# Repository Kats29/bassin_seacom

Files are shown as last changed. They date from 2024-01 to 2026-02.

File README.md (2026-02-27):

# Bassin Laboratoire SEACom - ISEN

Ce projet vise à remettre le bassin de test du laboratoire SEACom de l'ISEN au goût du jour. Pour cela, une interface Web est déployée sur un serveur Ethernet hébergé sur une carte Beaglebone Black qui communique avec le bassin via un shield customisé.

## TODO

### Partie Logicielle

- écrire une suite de tests exhaustive qui permet de comprendre ce qui doit être envoyé par le backend en fonction des commandes exécutées
- définir les trames de messages dans la documentation
- compléter la description de cette documentation (à partir de "Redémarrage des commandes numériques (RESET)")

### Partie Matérielle

- Imprimer ou découper à la CNC le couvercle du boitier de la carte
- Ajouter la vitre plexi devant les LED
- Produire la nouvelle version de la carte électronique
- acheter les différents composant manquant pour autonomiser le boitier
	- [prise filtre 230V](https://fr.rs-online.com/web/p/filtres-iec/1676800?searchId=2fb21e5c-5856-4a20-a56e-df45db2b0a76) (ça sera serré mais normalement ça passe)
    - [Alim 5V](https://fr.rs-online.com/web/p/alimentations-a-decoupage/0413673?searchId=7ffa1f5d-4cfa-4edf-9e52-69dc6d7725a8)
    - connecteur DB9 de facade

## Installation

### Configuration de la carte Beaglebone

Premièrement, afin d'avoir accès à tous les ports GPIO de la carte, celle-ci doit être démarrée à partir d'une carte SD au lieu de sa mémoire interne. Pour ce faire, téléchargez [la dernière image de Debian pour Beaglenone Black](https://www.beagleboard.org/distros) et flashez-la sur votre carte SD. Faites attention de bien choisir une image et non pas un flasher eMMC (le nom devrait finir par `4GB microSD IoT`).

Puisque les dernières versions ont un serveur nginx préinstallé, c'est ce que ce projet va utiliser.

Afin de vous connecter au Beaglebone, connecter le câble ethernet à votre pc et configurer votre carte réseau pour avoir une IPv4 telle que 192.168.7.4, via la commande `sudo ifconfig enp3s0 192.168.7.4` (en remplaçant enp3s0 par le nom de votre interface réseau).

Une fois la carte SD insérée dans la Beaglebone et celle-ci branchée sur le même réseau que votre ordinateur, vous pourrez ouvrir une console `ssh` grâce à la commande suivante :

```sh
ssh debian@192.168.7.3
```

Le mot de passe par défaut est `temppwd`.

Afin de configurer nginx, ouvrez le fichier `/etc/nginx/sites-enabled/default` et remplacez la ligne `root /var/www` par `root /home/debian/dist`. Enregistrez le fichier.

Finalement, il faut ouvrir le port 3333 de la Beaglebone pour permettre la connection TCP entre l'interface et le backend :

```sh
sudo nft add table ip filter
sudo nft add chain ip filter INPUT { type filter hook input priority 0 \; }
sudo nft add rule ip filter INPUT tcp dport 3333 accept
sudo nft list ruleset # pour vérifier que les règles ont bien été appliquées
sudo nft list ruleset | sudo tee -a /etc/nftables.conf # pour les sauvegarder
```

Vous pouvez maintenant quitter la console `ssh` avec la commande :

```sh
exit
```

### Compilation du projet

La compilation nécessite d'avoir podman, podman-compose et git d'installés sur le pc.
Clonez et compilez le projet GitHub sur votre ordinateur avec les commandes suivantes :

```sh
git clone https://github.com/Kats29/bassin_seacom.git
cd bassin_seacom
podman build .
podman compose run --rm arm-builder
```

Une fois que le projet est bien compilé (penser à vérifier les logs pour cela) vous pouvez envoyer la release sur la Beaglebone via le script `./.send.sh`.

Tapez le mot de passe de la Beaglebone lorsqu'il vous est demandé.

Vous pouvez à présent rouvrir une console `ssh` pour démarrer le backend :

```sh
ssh debian@192.168.7.3
```

Tapez le mot de passe.

```sh
sudo systemctl restart backend.service
```

Si tout va bien, vous devez avoir quelque chose qui ressemble à ci-dessous en tapant la commande  `sudo systemctl status backend.service` :
```sh
● backend.service - Backend du bassin
     Loaded: loaded (/etc/systemd/system/backend.service; enabled; preset: enabled)
     Active: active (running) since Fri 2025-03-14 21:15:03 CET; 5s ago
   Main PID: 2041 (backend)
      Tasks: 1 (limit: 1024)
     Memory: 72.0K
        CPU: 61ms
     CGroup: /system.slice/backend.service
             └─2041 /home/debian/backend

Mar 14 21:15:03 bassin systemd[1]: Started backend.service - Backend du bassin.
Mar 14 21:15:03 bassin backend[2041]: Starting backend...
```

Si vous souhaitez éditer la configuration du service, elle se trouve ici `/etc/systemd/system/backend.service` et nécessite un redémarrage de systemctl via `sudo systemctl daemon-reload`.

### Accès à l'interface

Vous pouvez à présent vous connecter à l'interface depuis votre navigateur internet, en tapant `192.168.7.3:9090` dans la barre d'adresse.

## Branchement

### Installation de la Beaglebone

### Raccordement réseau

### Communication avec le bassin

## Documentation

Une fois le projet cloné, la documentation technique du code peut être générée grâce à la commande :

```sh
make doc
```

La documentation devrait s'ouvrir dans un navigateur. Sinon, elle peut être visualisée dans un navigateur en ouvrant les fichiers `index.html` générés dans `target/doc/common`, `target/armv7-unknown-linux-musleabihf/doc/backend` et `target/wasm32-unknown-unknown/doc/frontend`

## Utilisation

L'accès se fait via deux plateformes : [cockpit](https://192.168.7.3:9090/system) pour le monitoring et le [site web pour le contrôle des bras](http://192.168.7.3/).

Interface de contrôle

### Apparence et organisation

L'interface est constituée d'une seule vue, qui est séparée en trois zones : une vue centrale, et deux panneaux latéraux. En cas de nécéssité, une fenêtre d'erreur peut également s'ouvrir devant la vue centrale.

#### Vue centrale

La vue centrale représente une visualisation de l'état actuel du bassin, ainsi que des commandes prévues.

Sa partie supérieure montre une vue du dessus en séparant les moitiés droite et gauche du bassin. La même séparation est visible sur la partie inférieure, qui elle montre une vue de côté du bassin (pour visualiser la profondeur).

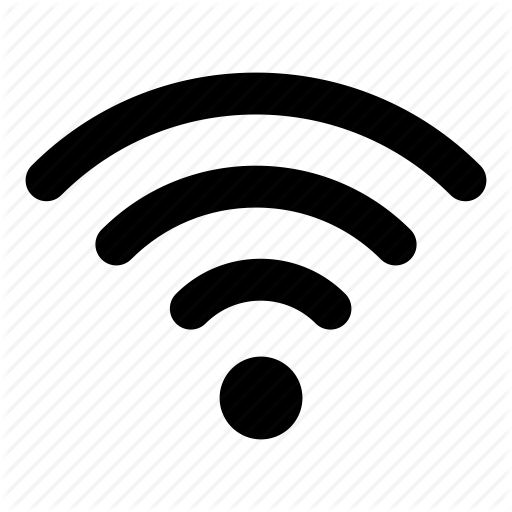
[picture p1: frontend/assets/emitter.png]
Les cadres noirs délimitent les zones où chacun des deux bras peut se déplacer, et les symboles  en noir symbolisent la position actuelle de chaque bras. Les symboles  grisés montrent le prochain mouvement pouvant être ajouté.

#### Panneau gauche

Le panneau latéral gauche montre deux choses :

* Les coordonnées du prochain mouvement à ajouter pour chaque bras.

* L'état actuel du bassin, sous formes d'indicateurs colorés (rouges ou verts, gris si le bassin n'est pas connecté).
	* En face de chaque coordonnée, un indicateur passe au rouge si un mouvement est en cours sur cet axe.
	* Sous les coordonnées, d'autres informations sont données sous cette forme.

#### Panneau droit

Le panneau latéral droit montre simplement la liste des mouvement prévus pour chaque bras, dans l'ordre chronologique.

#### Fenêtre d'erreur

### Commandes d'alimentation

La première chose à faire pour allumer le bassin est de le mettre physiquement sous tension. Une fois que c'est fait, l'alimentation peut être contrôlée à distance par l'interface.

#### Allumer le bassin

Pour allumer le bassin, allez dans le menu `Alimentation` et cliquez sur `Démarrer`. Après un démarrage de cette façon, une commande de RESET (expliquée plus loin) et de remise à l'origine doivent obligatoirement être effectuées dans cet ordre.

Après appui, les indicateurs `Bassin alimenté` et `Bassin démarré` devraient être au vert.

#### Éteindre le bassin

Une fois le bassin sous tension et démarré, le menu `Alimentation` devrait contenir un bouton `Arrêter`, qui doit éteindre le bassin.

Après appui, l'indicateur `Bassin démarré` devrait repasser au rouge.

#### Redémarrage des commandes numériques (RESET)

### Gestion des mouvements

#### Ajouter un mouvement

#### Supprimer un mouvement

#### Modifier un mouvement

### Effectuer un mouvement

#### Commandes générales

#### Commandes par bras

#### Commandes par axe

### Sauvegarde et importation de positions

#### Sauvegarder la configuration

#### Importer une configuration

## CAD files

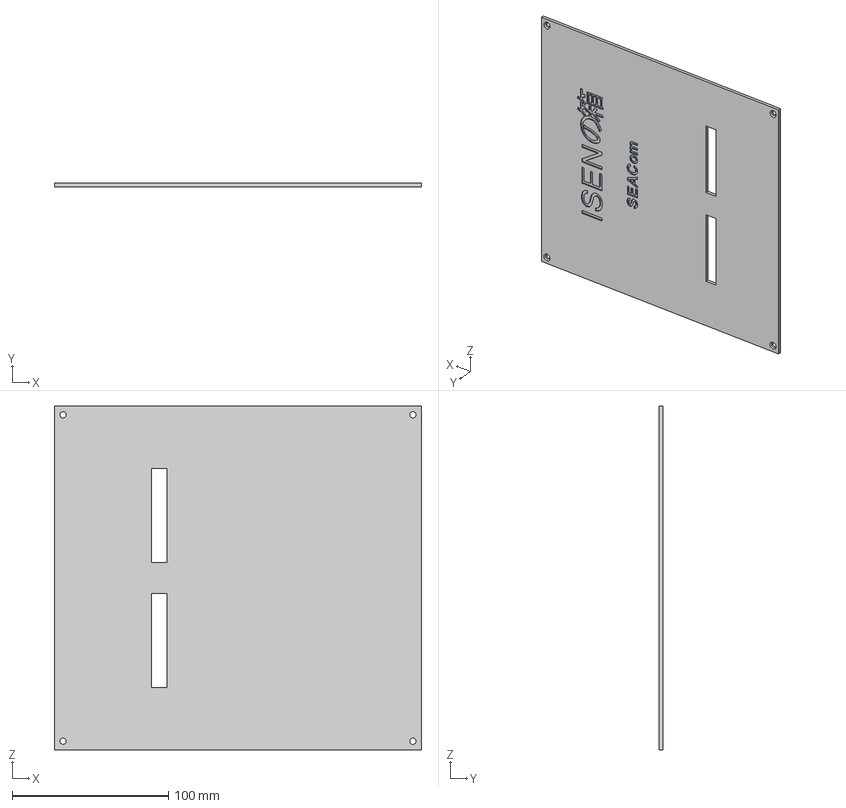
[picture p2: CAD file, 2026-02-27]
modelisation/boitier/couvercle.step
235.0 x 2.50 x 220.0 mm

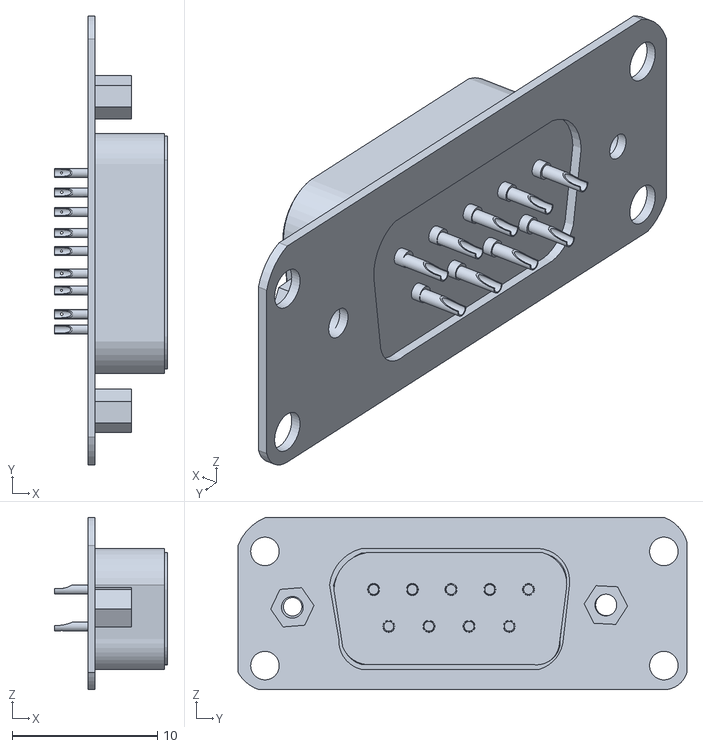
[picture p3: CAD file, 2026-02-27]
modelisation/connecteur_DB9.stl
7.80 x 31.0 x 11.9

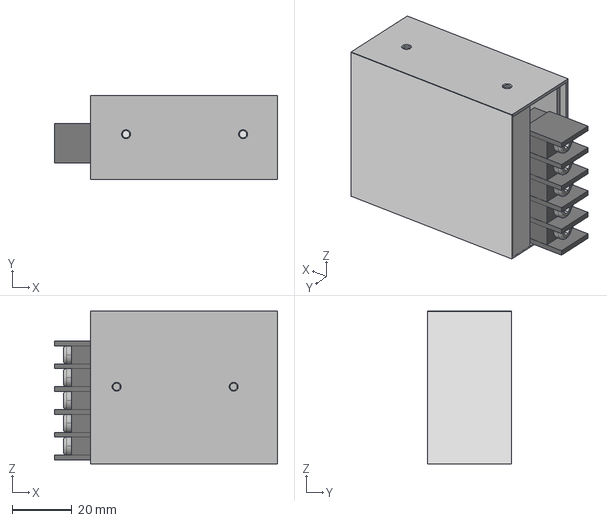
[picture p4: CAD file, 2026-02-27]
modelisation/Alim_5V.stp
74.5 x 28.0 x 51.0 mm

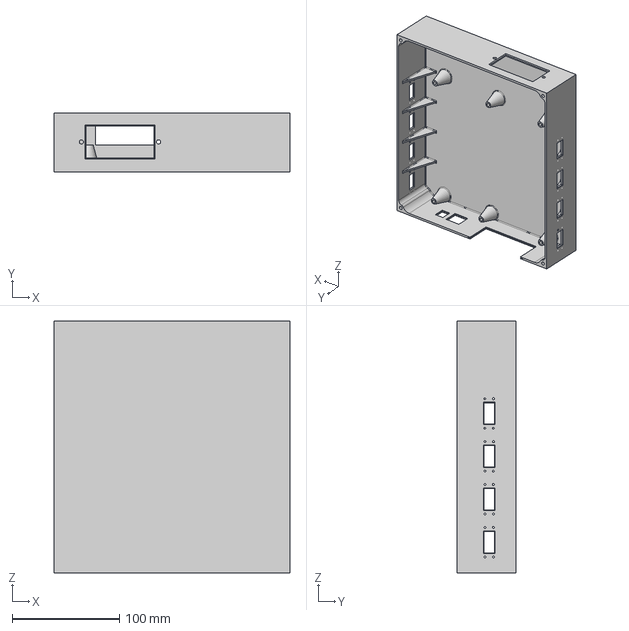
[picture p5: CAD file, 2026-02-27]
modelisation/boitier/Boitier.step
220.0 x 55.0 x 235.0 mm

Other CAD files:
modelisation/boitier/Boitier.f3d
modelisation/boitier/couvercle.f3d

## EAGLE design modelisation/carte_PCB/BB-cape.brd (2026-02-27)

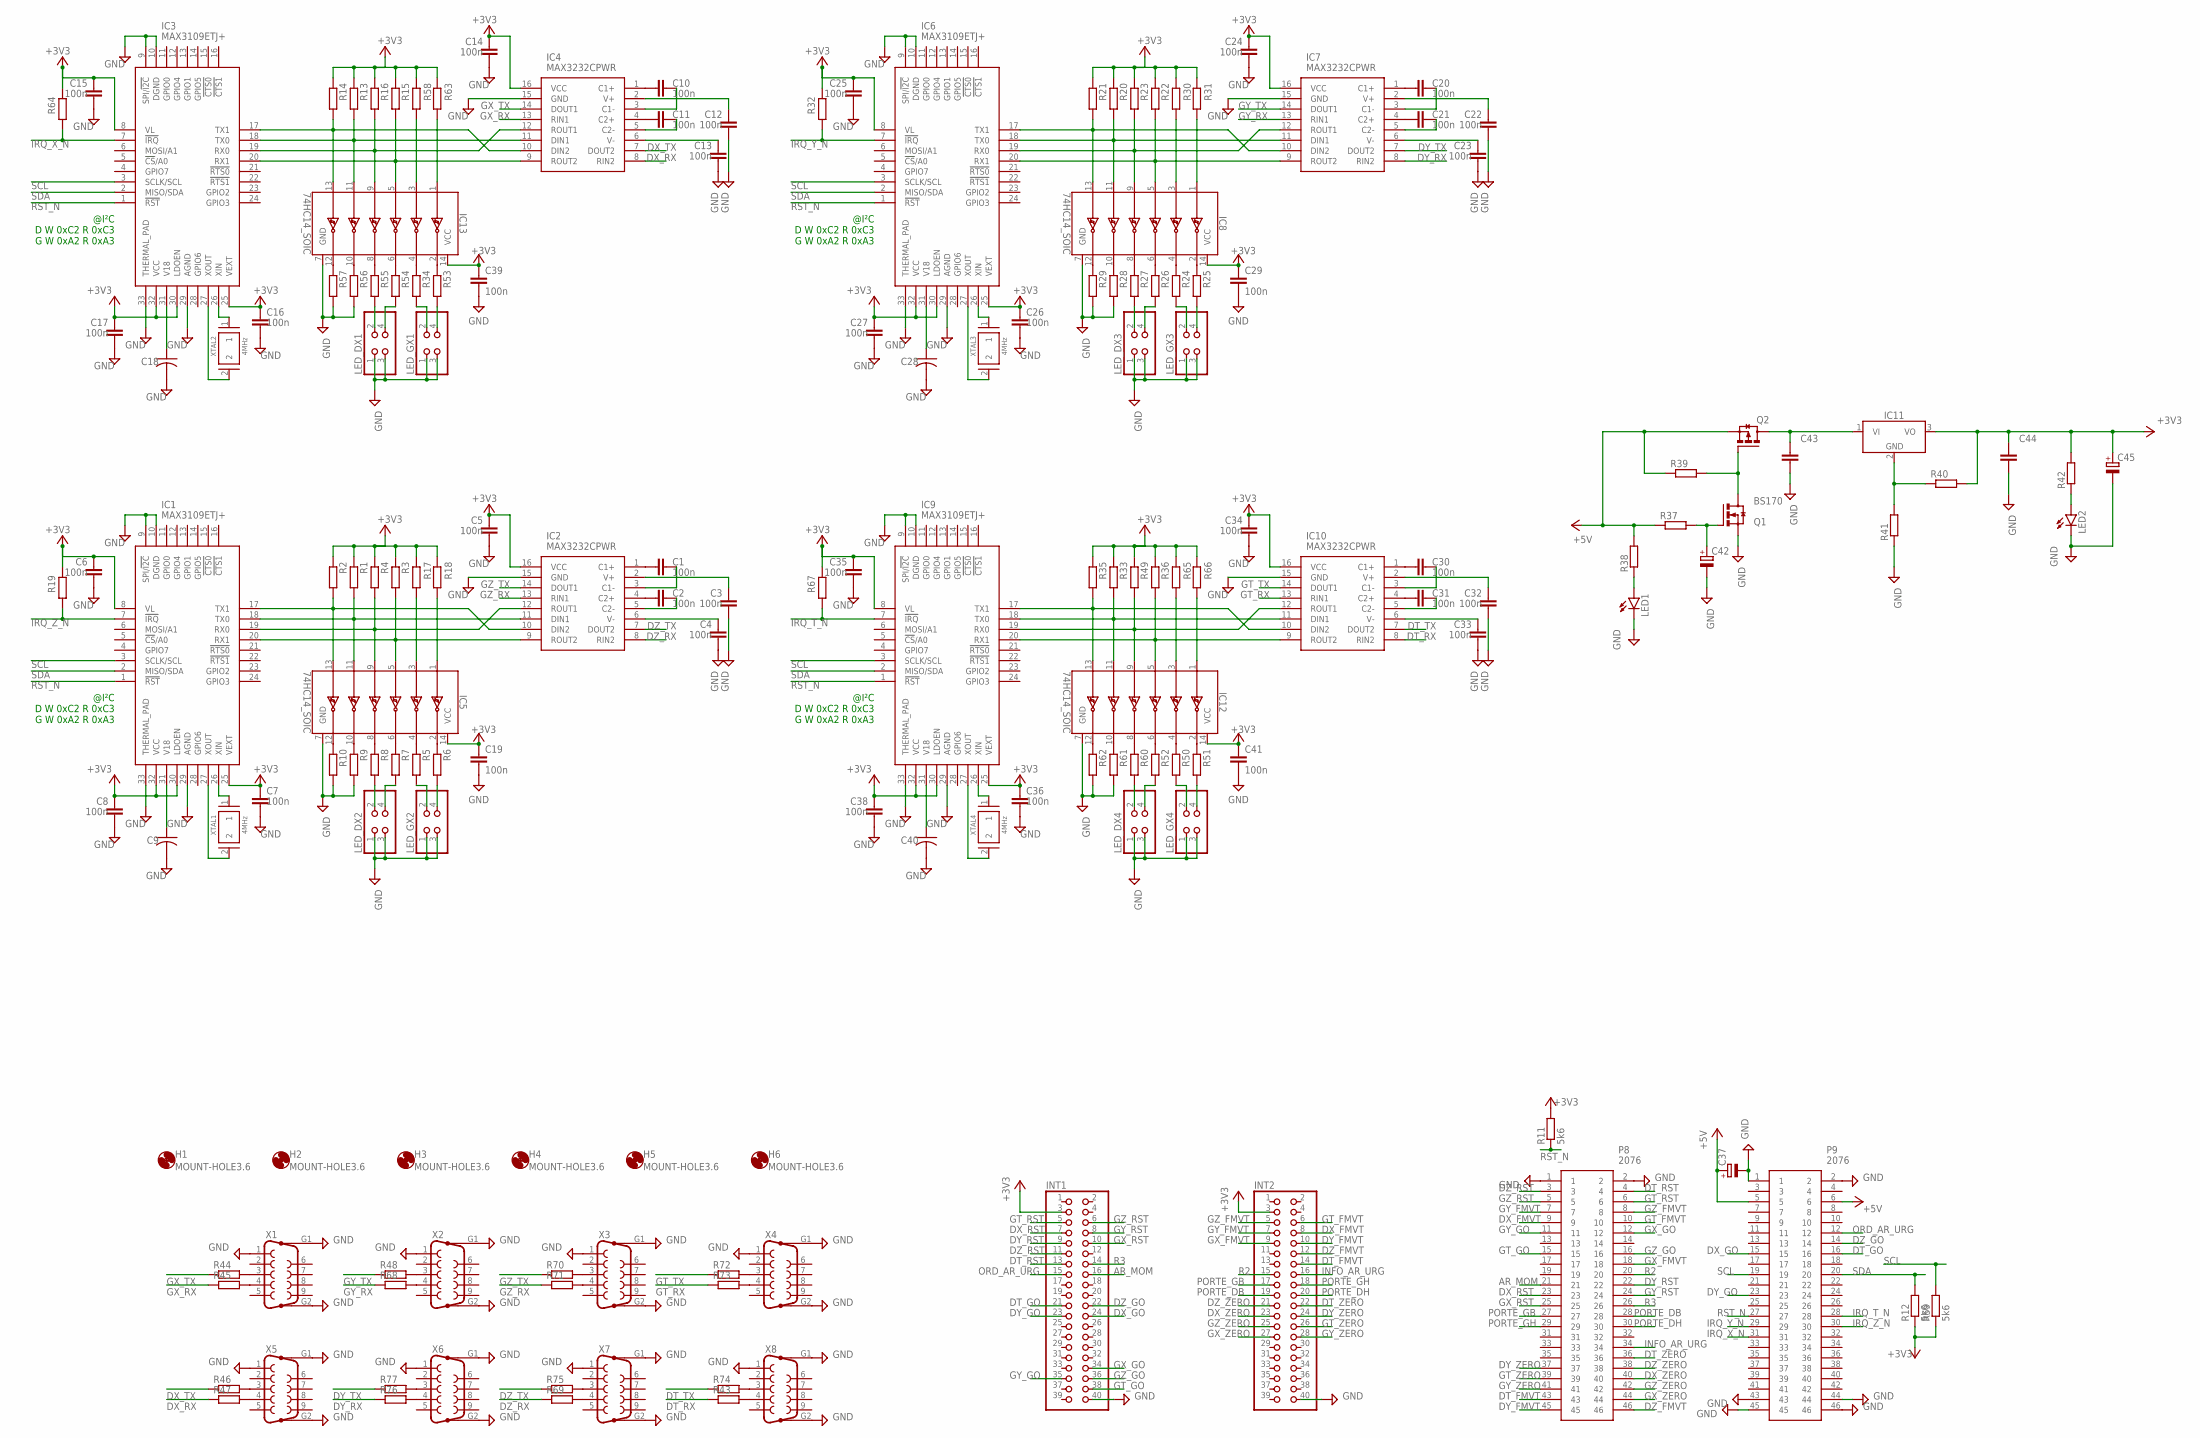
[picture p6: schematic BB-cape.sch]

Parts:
C1, C2, C3, C4, C5, C6, C7, C8, C10, C11, C12, C13, C14, C15, C16, C17, C19, C20, C21, C22, C23, C24, C25, C26, C27, C29, C30, C31, C32, C33, C34, C35, C36, C38, C39, C41: 100n; C0603
C9, C18, C28, C40: C-USC1206; C1206
C37, C42, C45: CPOL-EUE2.5-6; E2,5-6
C43, C44: C_CHIP-1210(3225-METRIC); CAPC3225X135
H1, H2, H3, H4, H5, H6: MOUNT-HOLE3.6; 3,6
IC1, IC3, IC6, IC9: MAX3109ETJ+; QFN50P500X500X80-33N
IC2, IC4, IC7, IC10: MAX3232CPWR; SOP65P640X120-16N
IC5, IC8, IC12, IC13: 74HC14_SOIC; SOIC127P600X175-14N
IC11: LM7805_TO220V; TO220V
INT1, INT2: PINHD-2X20; 2X20
LED1, LED2: TLLY4400; LED3MM
LED_DX1, LED_DX2, LED_DX3, LED_DX4: PINHD-2X2; 2X02
LED_GX1, LED_GX2, LED_GX3, LED_GX4: PINHD-2X2; 2X02
P8, P9: 2076; HDRV46W64P254_2X23_5842X500X87
Q1: BS170; TO92-3
Q2: IRF9540PBF; TO-220
R1, R2, R3, R4, R5, R6, R7, R8, R9, R10, R13, R14, R15, R16, R17, R18, R19, R20, R21, R22, R23, R24, R25, R26, R27, R28, R29, R30, R31, R32, R33, R34, R35, R36, R37, R38, R39, R40, R41, R42, R43, R44, R45, R46, R47, R48, R49, R50, R51, R52, R53, R54, R55, R56, R57, R58, R60, R61, R62, R63, R64, R65, R66, R67, R68, R69, R70, R71, R72, R73, R74, R75, R76, R77: R-EU_R0603; R0603
R11, R12, R59: 5k6; R0603
X1, X2, X3, X4, X5, X6, X7, X8: F09HP
XTAL1, XTAL2, XTAL3, XTAL4: 4MHz; XTAL1147X477X420N

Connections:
+3V3: C5.1, C6.1, C7.2, C8.2, C14.1, C15.1, C16.2, C17.2, C19.2, C24.1, C25.1, C26.2, C27.2, C29.2, C34.1, C35.1, C36.2, C38.2, C39.2, C41.2, C44.1, C45.+, IC1.8 (VL), IC1.25 (VEXT), IC1.30 (LDOEN), IC1.32 (VCC), IC2.16 (VCC), IC3.8 (VL), IC3.25 (VEXT), IC3.30 (LDOEN), IC3.32 (VCC), IC4.16 (VCC), IC5.14 (VCC), IC6.8 (VL), IC6.25 (VEXT), IC6.30 (LDOEN), IC6.32 (VCC), IC7.16 (VCC), IC8.14 (VCC), IC9.8 (VL), IC9.25 (VEXT), IC9.30 (LDOEN), IC9.32 (VCC), IC10.16 (VCC), IC11.3 (VO), IC12.14 (VCC), IC13.14 (VCC), INT1.3, INT2.3, R1.1, R2.1, R3.2, R4.2, R11.2, R12.1, R13.1, R14.1, R15.2, R16.2, R17.1, R18.1, R19.2, R20.1, R21.1, R22.2, R23.2, R30.1, R31.1, R32.2, R33.1, R35.1, R36.2, R40.2, R42.2, R49.2, R58.1, R59.1, R63.1, R64.2, R65.1, R66.1, R67.2
+5V: C37.+, P9.5, P9.6, Q2.S, R37.1, R38.2, R39.1
AR_MOM: INT1.16, P8.21
DT_FMVT: INT2.14, P8.43
DT_GO: INT1.21, P9.16
DT_RST: INT1.13, P8.4
DT_RX: IC10.8 (RIN2), R43.1
DT_TX: IC10.7 (DOUT2), R74.1
DT_ZERO: INT2.22, P8.36
DX_FMVT: INT2.8, P8.9
DX_GO: INT1.24, P9.15
DX_RST: INT1.7, P8.23
DX_RX: IC4.8 (RIN2), R47.1
DX_TX: IC4.7 (DOUT2), R46.1
DX_ZERO: INT2.23, P8.40
DY_FMVT: INT2.10, P8.45
DY_GO: INT1.23, P9.23
DY_RST: INT1.9, P8.22
DY_RX: IC7.8 (RIN2), R76.1
DY_TX: IC7.7 (DOUT2), R77.1
DY_ZERO: INT2.24, P8.37
DZ_FMVT: INT2.12, P8.46
DZ_GO: INT1.22, P9.14
DZ_RST: INT1.11, P8.3
DZ_RX: IC2.8 (RIN2), R69.1
DZ_TX: IC2.7 (DOUT2), R75.1
DZ_ZERO: INT2.21, P8.38
GND: C3.1, C4.2, C5.2, C6.2, C7.1, C8.1, C9.2, C12.1, C13.2, C14.2, C15.2, C16.1, C17.1, C18.2, C19.1, C22.1, C23.2, C24.2, C25.2, C26.1, C27.1, C28.2, C29.1, C32.1, C33.2, C34.2, C35.2, C36.1, C37.-, C38.1, C39.1, C40.2, C41.1, C42.-, C43.2, C44.2, C45.-, IC1.9 (SPI/!I2C), IC1.10 (DGND), IC1.29 (AGND), IC1.33 (THERMAL_PAD), IC2.15 (GND), IC3.9 (SPI/!I2C), IC3.10 (DGND), IC3.29 (AGND), IC3.33 (THERMAL_PAD), IC4.15 (GND), IC5.7 (GND), IC6.9 (SPI/!I2C), IC6.10 (DGND), IC6.29 (AGND), IC6.33 (THERMAL_PAD), IC7.15 (GND), IC8.7 (GND), IC9.9 (SPI/!I2C), IC9.10 (DGND), IC9.29 (AGND), IC9.33 (THERMAL_PAD), IC10.15 (GND), IC12.7 (GND), IC13.7 (GND), INT1.40, INT2.40, LED1.K (C), LED2.K (C), LED_DX1.1, LED_DX1.3, LED_DX2.1, LED_DX2.3, LED_DX3.1, LED_DX3.3, LED_DX4.1, LED_DX4.3, LED_GX1.1, LED_GX1.3, LED_GX2.1, LED_GX2.3, LED_GX3.1, LED_GX3.3, LED_GX4.1, LED_GX4.3, P8.1, P8.2, P9.1, P9.2, P9.43, P9.44, P9.45, P9.46, Q1.3 (S), R9.2, R10.2, R28.2, R29.2, R41.1, R56.2, R57.2, R61.2, R62.2, X1.1, X1.G1, X1.G2, X2.1, X2.G1, X2.G2, X3.1, X3.G1, X3.G2, X4.1, X4.G1, X4.G2, X5.1, X5.G1, X5.G2, X6.1, X6.G1, X6.G2, X7.1, X7.G1, X7.G2, X8.1, X8.G1, X8.G2
GT_FMVT: INT2.6, P8.10
GT_GO: INT1.38, P8.15
GT_RST: INT1.5, P8.6
GT_RX: IC10.13 (RIN1), R73.1
GT_TX: IC10.14 (DOUT1), R72.1
GT_ZERO: INT2.26, P8.39
GX_FMVT: INT2.9, P8.18
GX_GO: INT1.34, P8.12
GX_RST: INT1.10, P8.25
GX_RX: IC4.13 (RIN1), R45.1
GX_TX: IC4.14 (DOUT1), R44.1
GX_ZERO: INT2.27, P8.44
GY_FMVT: INT2.7, P8.7
GY_GO: INT1.35, P8.11
GY_RST: INT1.8, P8.24
GY_RX: IC7.13 (RIN1), R68.1
GY_TX: IC7.14 (DOUT1), R48.1
GY_ZERO: INT2.28, P8.41
GZ_FMVT: INT2.5, P8.8
GZ_GO: INT1.36, P8.16
GZ_RST: INT1.6, P8.5
GZ_RX: IC2.13 (RIN1), R71.1
GZ_TX: IC2.14 (DOUT1), R70.1
GZ_ZERO: INT2.25, P8.42
INFO_AR_URG: INT2.16, P8.34
IRQ_T_N: IC9.7 (!IRQ), P9.28, R67.1
IRQ_X_N: IC3.7 (!IRQ), P9.31, R64.1
IRQ_Y_N: IC6.7 (!IRQ), P9.29, R32.1
IRQ_Z_N: IC1.7 (!IRQ), P9.30, R19.1
unnamed: C3.2, IC2.2 (V+)
unnamed: C1.1, IC2.3 (C1-)
unnamed: C2.1, IC2.5 (C2-)
unnamed: C4.1, IC2.6 (V-)
unnamed: IC1.26 (XIN), XTAL1.1
unnamed: IC1.27 (XOUT), XTAL1.2
unnamed: C42.+, Q1.2 (G), R37.2
unnamed: LED_DX2.2, R8.2
unnamed: LED_DX2.4, R7.2
unnamed: LED_GX2.2, R5.2
unnamed: LED1.A, R38.1
unnamed: C12.2, IC4.2 (V+)
unnamed: Q1.1 (D), Q2.G, R39.2
unnamed: LED_GX2.4, R6.2
unnamed: C9.1, IC1.31 (V18)
unnamed: C10.1, IC4.3 (C1-)
unnamed: C11.1, IC4.5 (C2-)
unnamed: C13.1, IC4.6 (V-)
unnamed: IC3.26 (XIN), XTAL2.1
unnamed: IC3.27 (XOUT), XTAL2.2
unnamed: C43.1, IC11.1 (VI), Q2.D
unnamed: IC11.2 (GND), R40.1, R41.2
unnamed: IC1.17 (TX1), IC2.10 (DIN2), IC5.13 (6A), R2.2
unnamed: IC1.18 (TX0), IC2.11 (DIN1), IC5.11 (5A), R1.2
unnamed: IC1.19 (RX0), IC2.12 (ROUT1), IC5.9 (4A), R4.1
unnamed: LED_DX1.2, R55.2
unnamed: IC1.20 (RX1), IC2.9 (ROUT2), IC5.5 (3A), R3.1
unnamed: IC5.3 (2A), R17.2
unnamed: IC5.1 (1A), R18.2
unnamed: C1.2, IC2.1 (C1+)
unnamed: R44.2, X1.3
unnamed: LED2.A, R42.1
unnamed: R45.2, X1.4
unnamed: C2.2, IC2.4 (C2+)
unnamed: IC5.4 (2Y), R5.1
unnamed: IC5.2 (1Y), R6.1
unnamed: IC5.6 (3Y), R7.1
unnamed: IC5.8 (4Y), R8.1
unnamed: IC5.10 (5Y), R9.1
unnamed: IC5.12 (6Y), R10.1
unnamed: C22.2, IC7.2 (V+)
unnamed: C20.1, IC7.3 (C1-)
unnamed: C21.1, IC7.5 (C2-)
unnamed: C23.1, IC7.6 (V-)
unnamed: IC6.26 (XIN), XTAL3.1
unnamed: IC6.27 (XOUT), XTAL3.2
unnamed: LED_DX3.2, R27.2
unnamed: LED_DX3.4, R26.2
unnamed: LED_GX3.2, R24.2
unnamed: LED_GX3.4, R25.2
unnamed: C28.1, IC6.31 (V18)
unnamed: IC6.17 (TX1), IC7.10 (DIN2), IC8.13 (6A), R21.2
unnamed: IC6.18 (TX0), IC7.11 (DIN1), IC8.11 (5A), R20.2
unnamed: IC6.19 (RX0), IC7.12 (ROUT1), IC8.9 (4A), R23.1
unnamed: IC6.20 (RX1), IC7.9 (ROUT2), IC8.5 (3A), R22.1
unnamed: IC8.3 (2A), R30.2
unnamed: IC8.1 (1A), R31.2
unnamed: C20.2, IC7.1 (C1+)
unnamed: C21.2, IC7.4 (C2+)
unnamed: IC8.4 (2Y), R24.1
unnamed: IC8.2 (1Y), R25.1
unnamed: IC8.6 (3Y), R26.1
unnamed: IC8.8 (4Y), R27.1
unnamed: IC8.10 (5Y), R28.1
unnamed: IC8.12 (6Y), R29.1
unnamed: C32.2, IC10.2 (V+)
unnamed: C30.1, IC10.3 (C1-)
unnamed: C31.1, IC10.5 (C2-)
unnamed: C33.1, IC10.6 (V-)
unnamed: LED_DX1.4, R54.2
unnamed: LED_GX1.2, R34.2
unnamed: IC9.26 (XIN), XTAL4.1
unnamed: LED_GX1.4, R53.2
unnamed: C18.1, IC3.31 (V18)
unnamed: IC9.27 (XOUT), XTAL4.2
unnamed: LED_DX4.2, R60.2
unnamed: IC3.17 (TX1), IC4.10 (DIN2), IC13.13 (6A), R14.2
unnamed: R46.2, X5.3
unnamed: IC3.18 (TX0), IC4.11 (DIN1), IC13.11 (5A), R13.2
unnamed: LED_DX4.4, R52.2
unnamed: IC3.19 (RX0), IC4.12 (ROUT1), IC13.9 (4A), R16.1
unnamed: LED_GX4.2, R50.2
unnamed: LED_GX4.4, R51.2
unnamed: IC3.20 (RX1), IC4.9 (ROUT2), IC13.5 (3A), R15.1
unnamed: C40.1, IC9.31 (V18)
unnamed: IC9.17 (TX1), IC10.10 (DIN2), IC12.13 (6A), R35.2
unnamed: IC13.3 (2A), R58.2
unnamed: IC9.18 (TX0), IC10.11 (DIN1), IC12.11 (5A), R33.2
unnamed: IC9.19 (RX0), IC10.12 (ROUT1), IC12.9 (4A), R49.1
unnamed: IC13.1 (1A), R63.2
unnamed: IC9.20 (RX1), IC10.9 (ROUT2), IC12.5 (3A), R36.1
unnamed: IC12.3 (2A), R65.2
unnamed: R47.2, X5.4
unnamed: R48.2, X2.3
unnamed: R68.2, X2.4
unnamed: R70.2, X3.3
unnamed: R71.2, X3.4
unnamed: R69.2, X7.4
unnamed: R72.2, X4.3
unnamed: R73.2, X4.4
unnamed: IC12.1 (1A), R66.2
unnamed: C30.2, IC10.1 (C1+)
unnamed: C31.2, IC10.4 (C2+)
unnamed: IC12.4 (2Y), R50.1
unnamed: IC12.2 (1Y), R51.1
unnamed: IC12.6 (3Y), R52.1
unnamed: C10.2, IC4.1 (C1+)
unnamed: C11.2, IC4.4 (C2+)
unnamed: R74.2, X8.3
unnamed: R43.2, X8.4
unnamed: IC13.4 (2Y), R34.1
unnamed: IC13.2 (1Y), R53.1
unnamed: IC12.8 (4Y), R60.1
unnamed: IC12.10 (5Y), R61.1
unnamed: IC13.6 (3Y), R54.1
unnamed: IC13.8 (4Y), R55.1
unnamed: IC12.12 (6Y), R62.1
unnamed: R75.2, X7.3
unnamed: R76.2, X6.4
unnamed: R77.2, X6.3
unnamed: IC13.10 (5Y), R56.1
unnamed: IC13.12 (6Y), R57.1
ORD_AR_URG: INT1.15, P9.12
PORTE_DB: INT2.19, P8.28
PORTE_DH: INT2.20, P8.30
PORTE_GB: INT2.17, P8.27
PORTE_GH: INT2.18, P8.29
R2: INT2.15, P8.20
R3: INT1.14, P8.26
RST_N: IC1.1 (!RST), IC3.1 (!RST), IC6.1 (!RST), IC9.1 (!RST), P9.27, R11.1
SCL: IC1.3 (SCLK/SCL), IC3.3 (SCLK/SCL), IC6.3 (SCLK/SCL), IC9.3 (SCLK/SCL), P9.19, R59.2
SDA: IC1.2 (MISO/SDA), IC3.2 (MISO/SDA), IC6.2 (MISO/SDA), IC9.2 (MISO/SDA), P9.20, R12.2

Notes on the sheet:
@I²C D W 0xC2 R 0xC3 G W 0xA2 R 0xA3

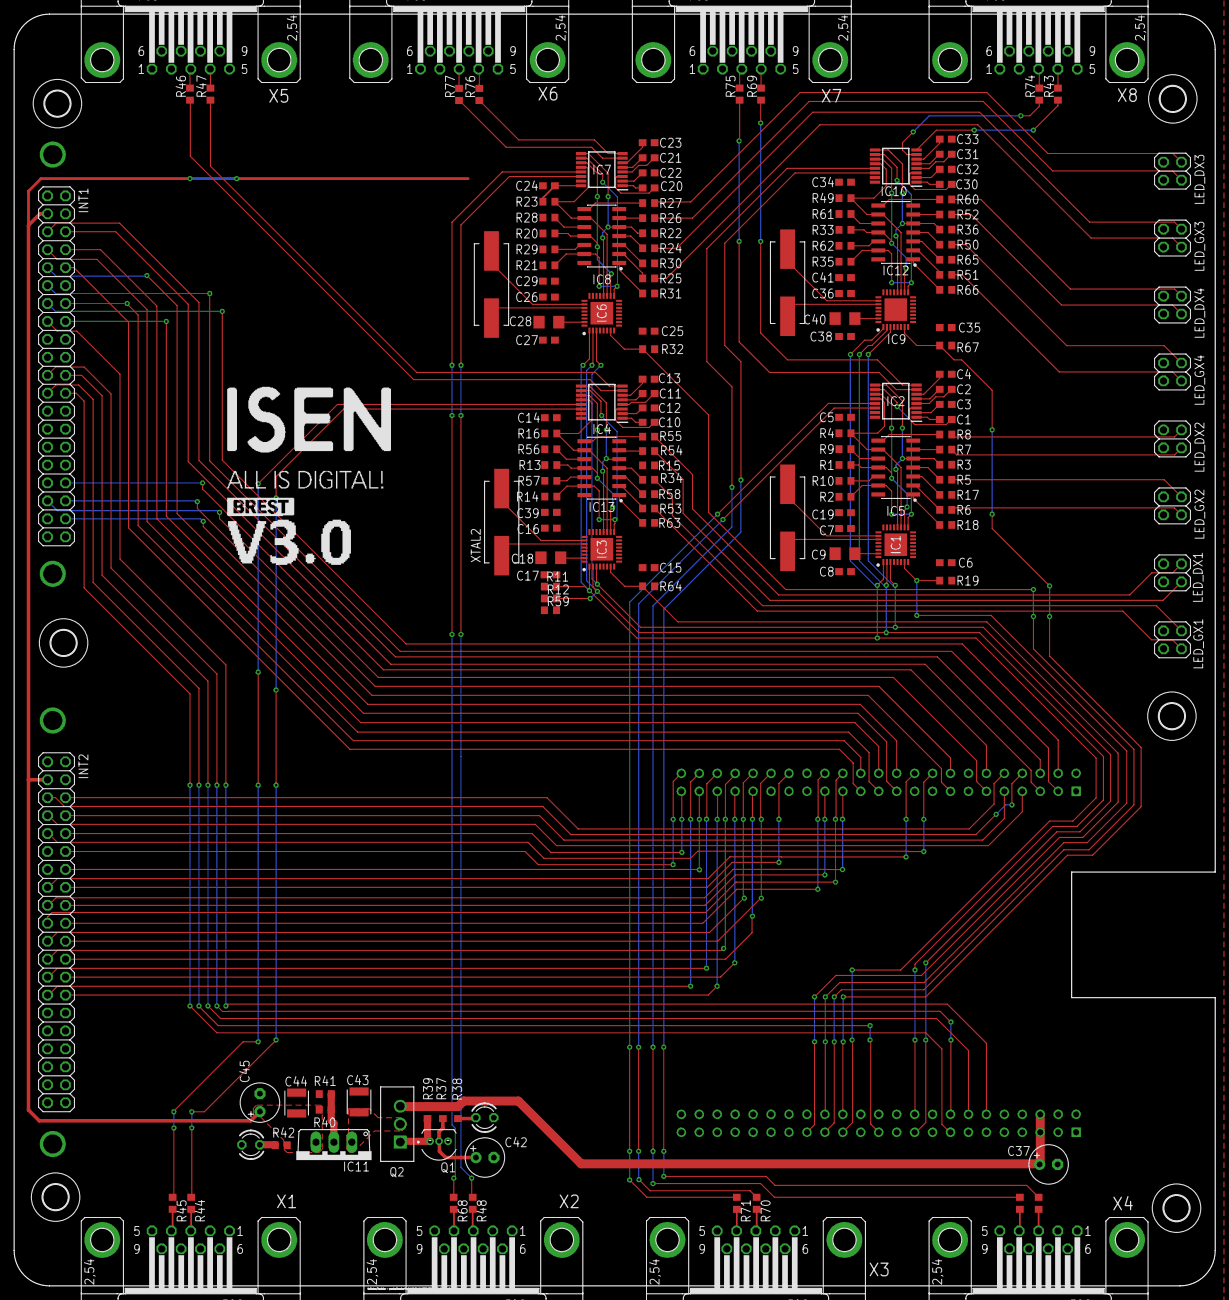
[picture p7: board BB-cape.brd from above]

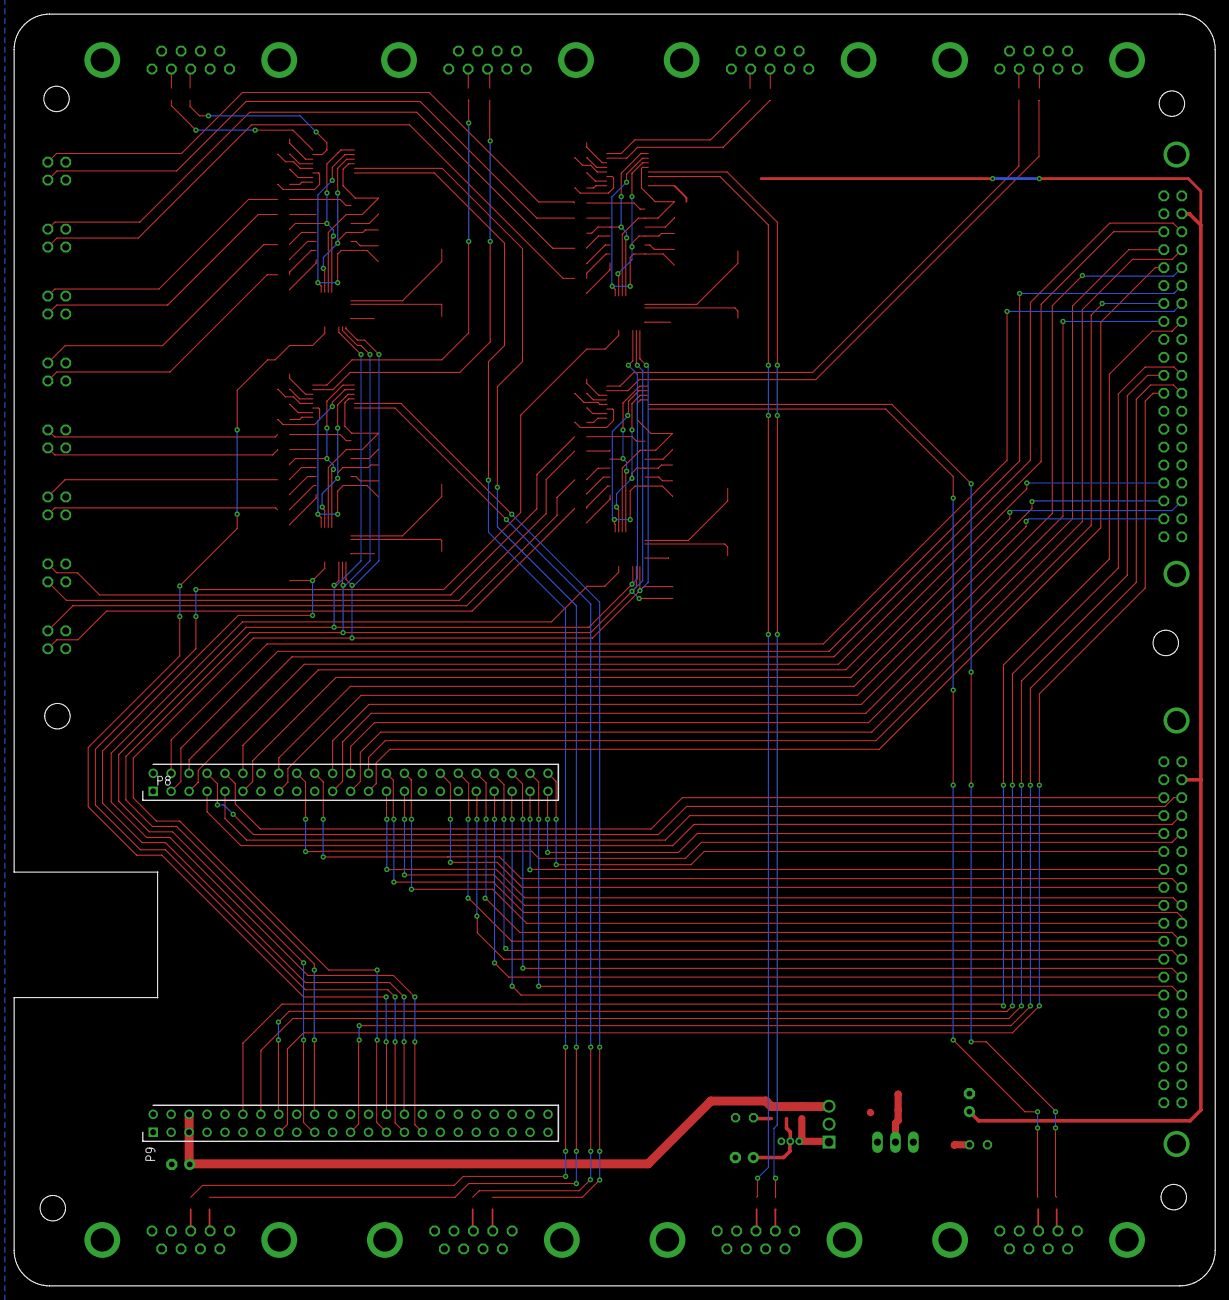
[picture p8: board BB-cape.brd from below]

Board: 2 copper layers, 170.0 x 180.0 mm, 169 parts (2 on the bottom side), 189 nets.

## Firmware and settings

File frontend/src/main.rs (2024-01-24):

#![warn(clippy::all, rust_2018_idioms)]
#![cfg(target_arch = "wasm32")]

mod app;

pub use app::TemplateApp;

fn main() {
    // Redirect `log` message to `console.log` and friends:
    eframe::WebLogger::init(log::LevelFilter::Debug)
        .expect("Couldn't start weblogger");

    let web_options = eframe::WebOptions::default();

    wasm_bindgen_futures::spawn_local(async {
        eframe::WebRunner::new()
            .start(
                "interface_bassin", // hardcode it
                web_options,
                Box::new(|cc| Box::new(TemplateApp::new(cc)))
            )
            .await
            .expect("failed to start eframe");
    });
}

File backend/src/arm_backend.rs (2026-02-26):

use std::cell::RefCell;
use std::sync::Mutex;

use async_recursion::async_recursion;
use futures::executor::block_on;
use sysfs_gpio::{Direction, Pin};

use common::definitions::Position;
use common::{
    definitions::{Command, Doors, DriverType, Status},
    error::HardwareError,
};

use crate::driver_cn_pin::DriverCnPin;
use crate::drivers_cn_rs232::DriversCnRs232;
use crate::error_handler::{pin_direction, pin_export, pin_read, pin_set_active_low, pin_write};

/// Liste des erreurs de l'update courante
pub static ERR_LIST: Mutex<RefCell<Vec<Result<(), HardwareError>>>> =
    Mutex::new(RefCell::new(vec![]));

/// Structure regroupant tout les drivers et les [`sysfs_gpio::Pin`] nécessaire pour faire fonctionné le bassin
pub struct ArmsBackend {
    driver_x_emetteur: DriverCnPin,
    driver_y_emetteur: DriverCnPin,
    driver_z_emetteur: DriverCnPin,
    driver_t_emetteur: DriverCnPin,

    driver_x_recepteur: DriverCnPin,
    driver_y_recepteur: DriverCnPin,
    driver_z_recepteur: DriverCnPin,
    driver_t_recepteur: DriverCnPin,

    driver_rs232: DriversCnRs232,

    pin_ar_mom: Pin,
    pin_on: Pin,
    pin_ordre_ar_urg: Pin,

    pin_info_etat: Pin,
    pin_info_ar_urg: Pin,
    pin_porte_gauche_bas: Pin,
    pin_porte_gauche_haut: Pin,
    pin_porte_droite_bas: Pin,
    pin_porte_droite_haut: Pin,
}

impl Default for ArmsBackend {
    fn default() -> Self {
        Self {
            driver_x_emetteur: DriverCnPin::default(),
            driver_y_emetteur: DriverCnPin::default(),
            driver_z_emetteur: DriverCnPin::default(),
            driver_t_emetteur: DriverCnPin::default(),

            driver_x_recepteur: DriverCnPin::default(),
            driver_y_recepteur: DriverCnPin::default(),
            driver_z_recepteur: DriverCnPin::default(),
            driver_t_recepteur: DriverCnPin::default(),

            driver_rs232: DriversCnRs232::default(),

            pin_ar_mom: Pin::new(0),
            pin_on: Pin::new(0),
            pin_ordre_ar_urg: Pin::new(0),
            pin_info_etat: Pin::new(0),
            pin_info_ar_urg: Pin::new(0),
            pin_porte_gauche_bas: Pin::new(0),
            pin_porte_gauche_haut: Pin::new(0),
            pin_porte_droite_bas: Pin::new(0),
            pin_porte_droite_haut: Pin::new(0),
        }
    }
}

impl ArmsBackend {
    pub fn new() -> Result<Self, HardwareError> {
        let mut arms = Self::default();

        arms.driver_x_emetteur = DriverCnPin::new(DriverType::EX)?;
        arms.driver_y_emetteur = DriverCnPin::new(DriverType::EY)?;
        arms.driver_z_emetteur = DriverCnPin::new(DriverType::EZ)?;
        arms.driver_t_emetteur = DriverCnPin::new(DriverType::ETHETA)?;

        arms.driver_x_recepteur = DriverCnPin::new(DriverType::RX)?;
        arms.driver_y_recepteur = DriverCnPin::new(DriverType::RY)?;
        arms.driver_z_recepteur = DriverCnPin::new(DriverType::RZ)?;
        arms.driver_t_recepteur = DriverCnPin::new(DriverType::RTHETA)?;

        arms.driver_rs232 = DriversCnRs232::new()?;

        arms.global_pin_creation();

        arms.global_pin_export()?;

        arms.global_pin_direction()?;

        Ok(arms)
    }

    fn global_pin_creation(&mut self) {
        self.pin_ordre_ar_urg = Pin::new(60);
        self.pin_on = Pin::new(61);
        self.pin_ar_mom = Pin::new(62);
        self.pin_info_etat = Pin::new(63);

        self.pin_info_ar_urg = Pin::new(81);
        self.pin_porte_gauche_bas = Pin::new(86);
        self.pin_porte_gauche_haut = Pin::new(87);
        self.pin_porte_droite_bas = Pin::new(88);
        self.pin_porte_droite_haut = Pin::new(89);
    }

    fn global_pin_export(&mut self) -> Result<(), HardwareError> {
        pin_export(self.pin_ar_mom)?;
        pin_export(self.pin_on)?;
        pin_export(self.pin_ordre_ar_urg)?;
        pin_export(self.pin_info_etat)?;
        pin_export(self.pin_info_ar_urg)?;

        pin_export(self.pin_porte_gauche_bas)?;
        pin_export(self.pin_porte_gauche_haut)?;
        pin_export(self.pin_porte_droite_bas)?;
        pin_export(self.pin_porte_droite_haut)
    }

    fn global_pin_direction(&self) -> Result<(), HardwareError> {
        pin_set_active_low(self.pin_on, true)?;
        pin_set_active_low(self.pin_ordre_ar_urg, true)?;
        pin_set_active_low(self.pin_ar_mom, true)?;
        pin_direction(self.pin_on, Direction::High)?;
        pin_direction(self.pin_ordre_ar_urg, Direction::Low)?;
        pin_direction(self.pin_ar_mom, Direction::Low)?;
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

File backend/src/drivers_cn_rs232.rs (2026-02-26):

//use std::fs::File;
//use i2c_linux::I2c;
use common::{definitions::DriverType, error::HardwareError};
use linux_embedded_hal::I2cdev;
use strum::IntoEnumIterator;
use sysfs_gpio::Direction::Low;
use sysfs_gpio::{Direction, Pin};

use crate::error_handler::{
    i2c_creation, i2c_read, i2c_set_slave, i2c_write, pin_direction, pin_export, pin_read,
    pin_write,
};

const ADDR_X_E: u8 = 0x6C;
const ADDR_Y_E: u8 = 0x61;
const ADDR_Z_E: u8 = 0x64;
const ADDR_T_E: u8 = 0x65;

const ADDR_X_R: u8 = 0x5C;
const ADDR_Y_R: u8 = 0x51;
const ADDR_Z_R: u8 = 0x54;
const ADDR_T_R: u8 = 0x55;

// #[derive(Copy, Clone)]
pub struct DriversCnRs232 {
    i2c_handler: Option<I2cdev>,
}

impl Default for DriversCnRs232 {
    fn default() -> Self {
        Self { i2c_handler: None }
    }
}

/// Drivers permettant la communication I2C au MAX3109 qui sera ensuite convertit en RS232
impl DriversCnRs232 {
    /// Renvoie l'adresse I2C du MAX3109 correspondant au type de drivers choisis
    fn get_i2c_addr_value(i2c_type: DriverType) -> u8 {
        return match i2c_type {
            DriverType::EX => ADDR_X_E,
            DriverType::EY => ADDR_Y_E,
            DriverType::EZ => ADDR_Z_E,
            DriverType::ETHETA => ADDR_T_E,
            DriverType::RX => ADDR_X_R,
            DriverType::RY => ADDR_Y_R,
            DriverType::RZ => ADDR_Z_R,
            DriverType::RTHETA => ADDR_T_R,
            _ => 0x00,
        };
    }

    /// Renvoie le pin ou l'interruption a lieu en fonction du type de drivers choisis
    fn get_iqr_pin(i2c_type: DriverType) -> Pin {
        match i2c_type {
            DriverType::RX | DriverType::EX => Pin::new(110),
            DriverType::EY | DriverType::RY => Pin::new(111),
            DriverType::EZ | DriverType::RZ => Pin::new(112),
            DriverType::ETHETA | DriverType::RTHETA => Pin::new(113),
            _ => Pin::new(0x00),
        }
    }

    pub fn new() -> Result<Self, HardwareError> {
        let mut driver = Self::default();
        driver.i2c_handler = Some(i2c_creation("/dev/i2c-2".to_string())?);
        let mut pin = Pin::new(110);
        pin_export(pin)?;
        pin_direction(pin, Direction::In)?;

        pin = Pin::new(111);
        pin_export(pin)?;
        pin_direction(pin, Direction::In)?;

        pin = Pin::new(112);
        pin_export(pin)?;
        pin_direction(pin, Direction::In)?;

        pin = Pin::new(113);
        pin_export(pin)?;
        pin_direction(pin, Direction::In)?;
        driver.configuration()?;
        Ok(driver)
    }
    /// Configure l'état de base des MAX3109 afin d'avoir des interruptions lors de la réception de nouvelle donnée.
    /// Retourne une [`HardwareError`] en cas de problème
    fn configuration(&mut self) -> Result<(), HardwareError> {
        let pin = Pin::new(115);
        pin_export(pin)?;
        pin_direction(pin, Low)?;
        let i2c_handler = match self.i2c_handler.as_mut() {
            None => Err(HardwareError::UnknownError("".to_string())),
            Some(a) => Ok(a),
        }?;
        pin_write(pin, 1)?;
        for dt in DriverType::iter() {
            i2c_set_slave(i2c_handler, Self::get_i2c_addr_value(dt) as u16, dt)?;
            match dt {
                DriverType::EX | DriverType::EY | DriverType::RX | DriverType::RY => {
                    i2c_write(i2c_handler, 0x1E, 0x1A, dt)?; // utilise la clock externe
                    i2c_write(i2c_handler, 0x1C, 26u8, dt)?; // utilise la clock externe
                    i2c_write(i2c_handler, 0x1B, 1u8, dt)?; // utilise la clock externe
                    i2c_write(i2c_handler, 0x0A, 0x08, dt)?; // interupt sur remplisage RxFifo
                    i2c_write(i2c_handler, 0x01, 0x40, dt)?;
                    i2c_write(i2c_handler, 0x0B, 0x03, dt)?;
                    i2c_read(i2c_handler, 0x02, dt)?;
                }

                DriverType::EZ | DriverType::ETHETA | DriverType::RZ | DriverType::RTHETA => {}
                _ => {}
            }
        }

        Ok(())
    }

    /// Ecrit sur l'I2C a l'adresse corespodant au driver choisis. Retourne une [`HardwareError`] en cas de problème.
    pub fn write_i2c(&mut self, data: [u8; 9], type_cn: DriverType) -> Result<(), HardwareError> {
        let i2c_addr = Self::get_i2c_addr_value(type_cn);
        let iqr_pin = Self::get_iqr_pin(type_cn);
        let i2c_handler = match self.i2c_handler.as_mut() {
            None => Err(HardwareError::UnknownError("".to_string())),
            Some(a) => Ok(a),
        }?;
        i2c_set_slave(i2c_handler, i2c_addr as u16, type_cn)?;
        i2c_read(i2c_handler, 0x12, type_cn)?;
        i2c_write(i2c_handler, 0x0A, 0xA, type_cn)?;
        i2c_write(i2c_handler, 0x0A, 0x8, type_cn)?;
        i2c_read(i2c_handler, 0x02, type_cn)?;
        for n in data.into_iter() {
            i2c_write(i2c_handler, 0x09, 0x02, type_cn)?; // Desactive le
                                                          // transmetteur
            i2c_write(i2c_handler, 0x00, n, type_cn)?;
            i2c_write(i2c_handler, 0x09, 0x00, type_cn)?; // Reactive le transmetteur

            while pin_read(iqr_pin)? != 0 {}

            i2c_read(i2c_handler, 0x02, type_cn)?;

            let g = i2c_read(i2c_handler, 0x00, type_cn)?;

            if g != n {
                return Err(HardwareError::BadI2cResponse(type_cn, g, n));
            }
        }
        Ok(())
    }

    // pub fn read_i2c_origin(&mut self, type_cn: DriverType) -> Result<(), HardwareError> {
    //     let i2c_addr = Self::get_i2c_addr_value(type_cn);
    //     let irq_pin = Self::get_iqr_pin(type_cn);
    //     let i2c_handler = match self.i2c_handler.as_mut() {
    //         None => {
    //             Err(HardwareError::UnknownError("".to_string()))
    //         }
    //         Some(a) => {
    //             Ok(a)
    //         }
    //     }?;

    //     i2c_set_slave(i2c_handler, i2c_addr as u16, type_cn)?;
    //     while i2c_read(i2c_handler, 0x12, type_cn)? == 0 || pin_read(irq_pin)? != 0 {}
    //     if i2c_read(i2c_handler, 0x00, type_cn)? != 0x00 {
    //         return Err(HardwareError::UnknownError("Mauvais retour d'origine".to_string()));
    //     }
    //     Ok(())
    // }
    pub fn x_to_bytes(float: f32) -> [u8; 9] {
        let x = ((-6025.0 * float.abs()) as isize + 8539473) as usize;
        let mut bytes: [u8; 9] = [0x08, 0x51, 0x00, 0x01, 0x00, 0x00, 0x00, 0x87, 0xff];
        bytes[4] = (x >> 16) as u8;
        bytes[5] = (x >> 8) as u8;
        bytes[6] = (x & 0xff) as u8;
        return bytes;
    }

    pub fn y_to_bytes(float: f32) -> [u8; 9] {
        let y = ((-6025.0 * float) as isize + 2984423) as usize;
        let mut bytes: [u8; 9] = [0x08, 0x51, 0x00, 0x01, 0x00, 0x00, 0x00, 0x87, 0xff];
        bytes[4] = (y >> 16) as u8;
        bytes[5] = (y >> 8) as u8;
        bytes[6] = (y & 0xff) as u8;
        return bytes;
    }
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

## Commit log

2024-01-23 Implémentation des drivers dans le backend, et ajout des fonctions reset, zereo et ar_mom pour DriverCn
    [backend.rs, main.rs]
2024-01-26 Création de ArmBackend
2024-01-26 Ajout de la fonction update dans ArmBackend
2024-01-26 added drivers
2024-01-26 Commencement du drivers pour la communication en RS323, via i2c
2024-01-29 Fin du drivers pour la communication en RS323, via i2c Mise a jour de la classe AmrsBackend pour l'implémenter
2024-02-02 Update du système d'erreur sur le backend Implémentation du système de commande sur la backend
2024-02-02 Goulven touche au frontend (plus de drifting, frame des différentes vue faite par une fonction, création de problèmes au niveau de l'affichage tu théta)
    [app.rs, arm_backend.rs, definitions.rs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]
2024-02-02 Goulven retouche au frontend (et il règle les problèmes au niveau de l'affichage du théta qu'il avait créé)
2024-02-07 Mise ne place du threading tcp pour le backend
2024-02-08 Mise ne place du threading tcp pour le backend partie 2
2024-02-09 Mise en place d'un système de fichier de log
2024-02-09 Petite maj tu index.html pour enlever des warning
2024-02-09 Création de la structure de status
2024-03-05 Amélioration du système de log, et création d'un dossier de log a part
2024-03-06 Ammélioration du polling pour le status : envoie du status que si changement Configuration des drivers I2C vers RS232
2024-03-06 Ajout des fonctions origin_X et move_next_X
2024-03-06 Ajout des commandes pour les cn dans l'interface
2024-03-06 Ajout d'une parti de la list des position suivantes
2024-03-07 Début side panel pour affichage de la liste
2024-03-07 Ajout du chemin sur le panneau de visualisation
2024-03-07 Nouveau format pour la position
2024-03-07 Ajout de l'attente de fin de mouvement avant chagement affichage
2024-03-07 pour de vrai cette fois
2024-03-07 changement de couleur des chemins pendant les mouvements
2024-03-08 fin de l'ajout de l'attente de fin de mouvement avant chagement affichage
2024-03-08 Remplacement des sends par les fonctions associées
2024-03-08 Réglage du décalage des vues
2024-03-08 ajout de la gestion de fichiers (marche pas)
2024-03-09 Gestion de fichiers qui fonctionne
2024-03-26 Réglage partielle suppression dans vec de move
2024-03-26 Changement du format JSON des fichiers enregistrés et mise en place d'une erreur si format invalide
2024-03-26 Ajout de commentaire pour la doc
2024-03-27 J'ai tout règlé les problèmes
2024-03-29 i2c disable transmit during write
2024-03-29 Le backend qui marche avec la comm RS232
2026-02-26 feat: migrated backend deps from websocket to tungstenite and i2c-linux to i2cdev because old crates were not maintained anymore + some linting
2026-02-27 ADD 3D modeling files. enclosure for the pcb
    [Alim_5V.stp, Boitier.f3d, Boitier.step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]
2026-02-27 ADD 3D modeling files for PCB and electronic makefile
    [BB-cape.brd, BB-cape.sch]
